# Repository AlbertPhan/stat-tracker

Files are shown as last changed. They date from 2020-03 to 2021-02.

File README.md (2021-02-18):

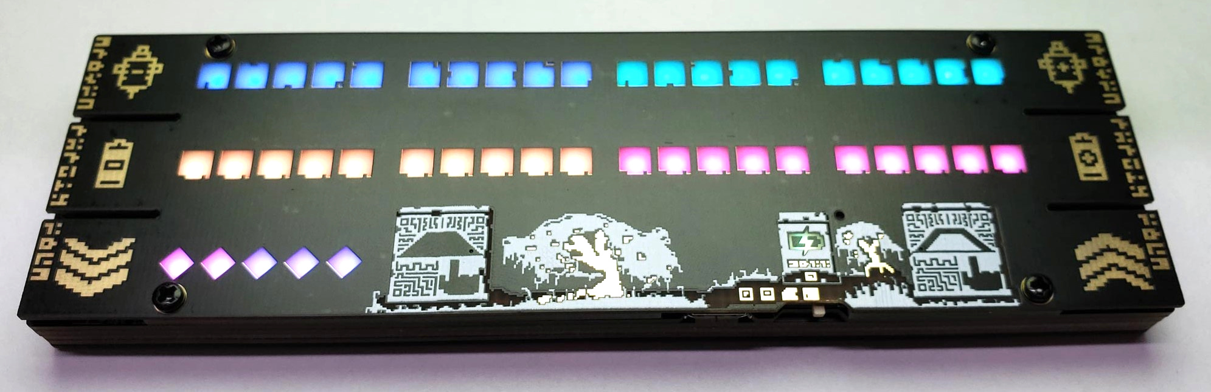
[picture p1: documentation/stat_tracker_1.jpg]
Stat Tracker


### For more pictures and info see:
www.pegasusprototyping.ca/stattracker

# Stat Tracker
The ***Stat Tracker*** is a portable battery powered device that keeps track of ***health, energy, and dashes*** for the Hyper Light Drifter Table Top Role Playing Game. Although it was designed with Hyper Light Drifter in mind, it could be used in other table top games like Dungeons and Dragons. 

Features:

 - Tracks 40 points of Health and Energy and 10 points in Dashes
 - Bright RGB leds for each icon
 - Custom art in Hyper Light Drifter theme
 - Unique Slim PCB sandwich construction with special icons for LED diffusion
 - 6 physical pcb buttons to add/subtract points
 - 2 touch buttons for brightness control
 - Customizable colour palettes including colourblind modes
 - USB micro for charging
 - 8 hours of battery life on default brightness and battery charge indicator icon
 - Stats are saved on power off.

 # Code

 The stat tracker uses a very cheap 50 cent chinese mcu called the CH552. The tool chain setup is explained in https://github.com/Blinkinlabs/ch554_sdcc.

 The stat tracker code is contained in the examples folder "examples/stat_tracker"

 Some c files were created/modified to help use the ch552 such as:
 - button.c     usage of buttons and their states
 - touch.c      touch button usage
 - timer.c      set up timers for millis()

 # Eagle Source files

Eagle Source files are included. (Eagle Version 9.6.1 was used). See README in Eagle files for bom/board information.

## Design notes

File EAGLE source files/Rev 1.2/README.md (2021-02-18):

# Boards
For a full PCB sandwich you will need:
1 Top
1 Middle
1 Bottom
3 Spacers
1 Box Art
Send additional info the board house such as led pinout png and note that the pads on the bottom of the bottom board are supposed to have solder mask (no exposed pad) over them.

# BOM
Bom is located in the GERBER bottom assembly "\Rev 1.2\Gerber\HLD-stat-tracker-bottom_2020-12-04\CAMOutputs\Assembly\HLD-stat-tracker-bottom-BOM.csv"
LEDS used are a 2020 type with SK6812 like pinout (not the same as ws2812-2020). Please triple check the pinouts if you are using something other than leds in the BOM.

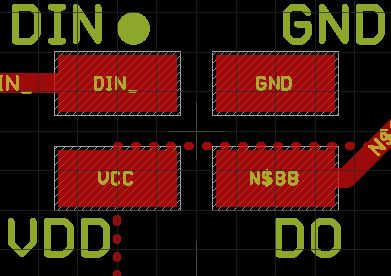
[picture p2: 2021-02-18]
EAGLE source files/Rev 1.2/Gerber/KTR-1010 Pinout.JPG

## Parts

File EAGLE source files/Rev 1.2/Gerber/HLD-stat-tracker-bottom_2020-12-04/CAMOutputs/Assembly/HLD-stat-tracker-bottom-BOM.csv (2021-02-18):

Qty | Value | Device | Package | Parts | Description | MANUFACTURER | PARTNO | POPULARITY | PROD_ID | SPICEPREFIX | VALUE
1 |  | PTC0805 | WCAP-CSGP_0805_H1.25_R | PTC1 | PTC (Resettable Fuse) | Jinrui Electronic Materials Co. | JK-SMD0805-075
1 |  | USB_MICRO-BSINK-PLATE | USB-B-MICRO-SMD-SINK-PLATE | J1 | USB Type Micro-B Connector | Jing Extension of the Electronic Co. | C40957
2 | 100nF | C-EUC0805K | C0805K | C1 | C2 | CAPACITOR | European symbol |  | ?
6 | 10k | R-US_R0805S | R0805S | R1 | R3 | R5 | R6 | R7 | R8 | RESISTOR | American symbol |  | ?
4 | 10uF | C-EUC0805K | C0805K | C3 | C4 | C5 | C9 | CAPACITOR | European symbol |  | ?
1 | 2k | R-US_R0805S | R0805S | R2 | RESISTOR | American symbol |  | ?
1 | 3.9k | R-US_R0805S | R0805S | R4 | RESISTOR | American symbol |  | ?
1 | 4.7uH | INDUCTOR2012 | BEADC2012X105N | L1 | NRS6014 Inductor | INPAQ | C315723
1 | 7MM-SLIDE-SWITCH | 7MM-SLIDE-SWITCH | 7MM-SMD-SLIDE-SWITCH | PWR | PN: SSSS811101 7mm SMD SLIDE SWITCH | XKB Enterprise | SK-3296S-01-L1
1 | AP2302B | MOSFET-NREFLOW | SOT23-R | Q2 | N-Channel Mosfet | HX(hengjiaxing) | AP2302B
1 | B5819LW | DIODESOD-123 | SOD-123 | D1 | Diode | Guangdong Hottech | B5819LW
1 | CH552SOP16-HANDSOLDER | CH552SOP16-HANDSOLDER | SOP16-HANDSOLDER | IC1 | Microcontroller | WCH(Jiangsu Qin Heng) | CH552G
1 | HX2301A | MOSFET-P | SOT23-R | Q1 | P-Channel Mosfet | HX(hengjiaxing) | HX2301A
46 | KTR-1010RGBC-1812-4 | KTR-1010RGBC-1812-4 | SK6812-2020 | STATUS | U$1 | U$2 | U$3 | U$4 | U$5 | U$6 | U$7 | U$8 | U$9 | U$10 | U$11 | U$12 | U$13 | U$14 | U$15 | U$16 | U$17 | U$18 | U$19 | U$20 | U$21 | U$22 | U$23 | U$24 | U$25 | U$26 | U$27 | U$28 | U$29 | U$30 | U$31 | U$32 | U$33 | U$34 | U$35 | U$36 | U$37 | U$38 | U$39 | U$40 | U$41 | U$42 | U$43 | U$44 | U$45 | Addressable RGD LED similiar to SK6812-2020. | KTRLIGHT | KTR-1010RGBC-1812-4
1 | MCP73832 | MCP73831 | SOT23-5 | U1 | Miniature single cell | fully integrated Li-Ion | Li-polymer charge management controller | Microchip Tech | MCP73832
1 | MT3540 | AP3012 | SOT23-5 | U2 | AP3012 | XI'AN Aerosemi Tech | MT3540
3 | SPRING-CONTACT | SPRING-CONTACT | 818000905-SPRING-CONTACT | GND | TIN1 | TIN2 |  | ECT | ECT818000905
7 | TACTSW | TACTSW | 3MM-TACT | BOOT | DP+ | DP- | EP+ | EP- | HP+ | HP- |  | SHOU HAN | TS3315A
4 |  |  |  |  | M2 Threaded Standoff OD 3.12mm length 4mm
4 |  |  |  |  | M2 Button Philips Head 3 mm length black
4 |  |  |  |  | M2 Button Philips Head 6 mm length black
1 |  |  |  |  | Lipo Battery 630 Mah 403443 (4 mm thick x 34 mm x 43 mm)
4

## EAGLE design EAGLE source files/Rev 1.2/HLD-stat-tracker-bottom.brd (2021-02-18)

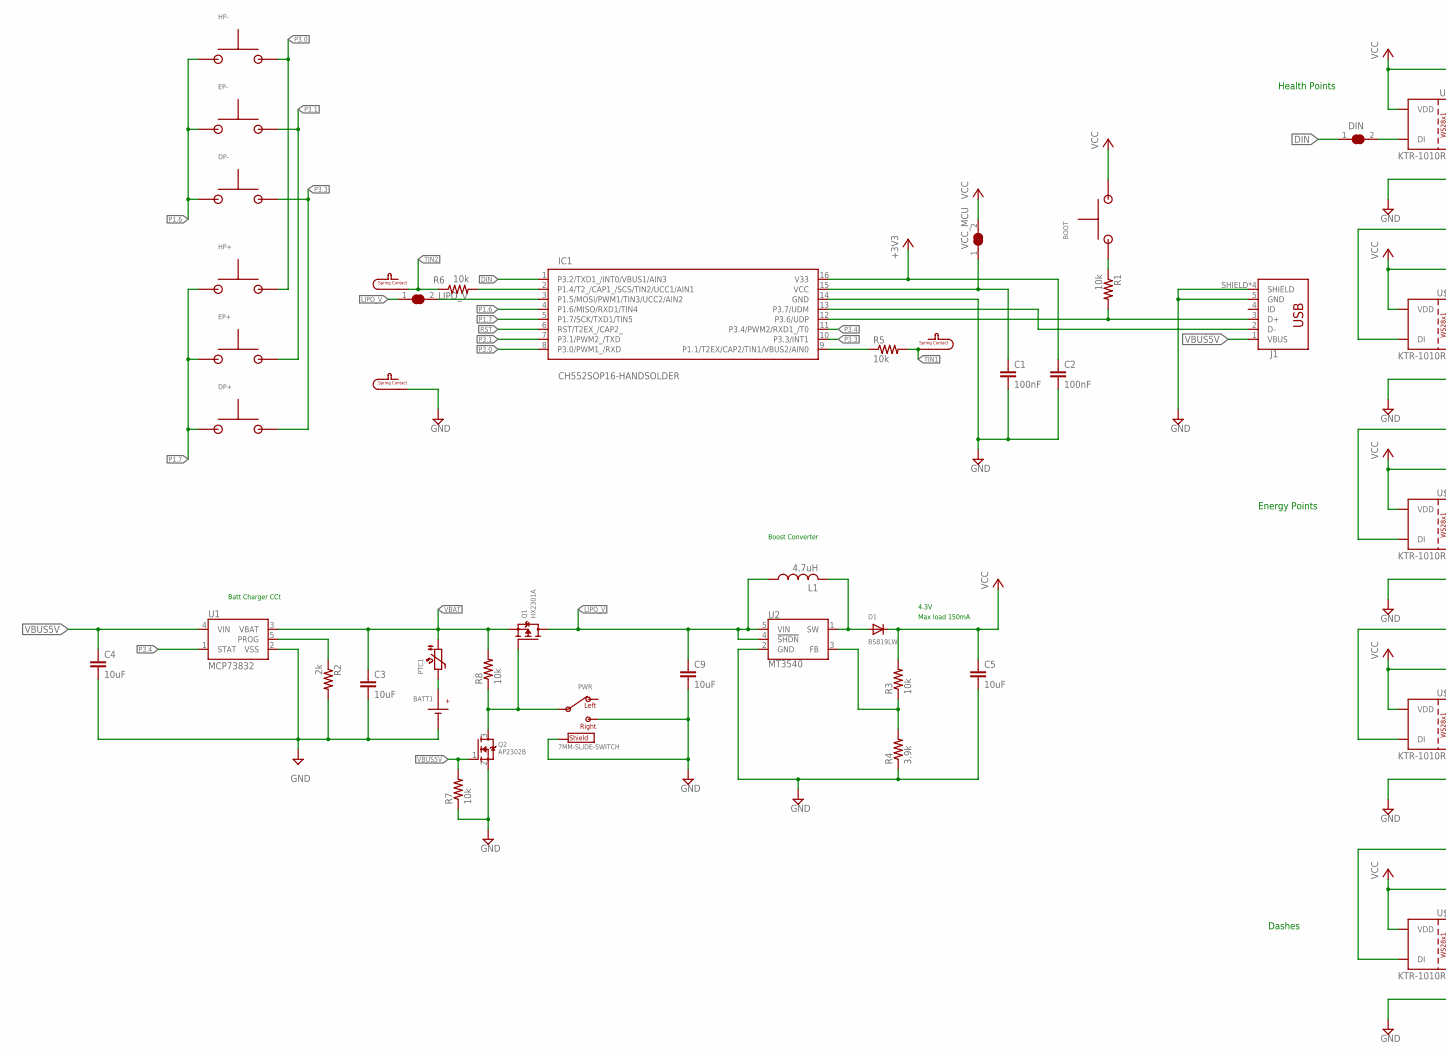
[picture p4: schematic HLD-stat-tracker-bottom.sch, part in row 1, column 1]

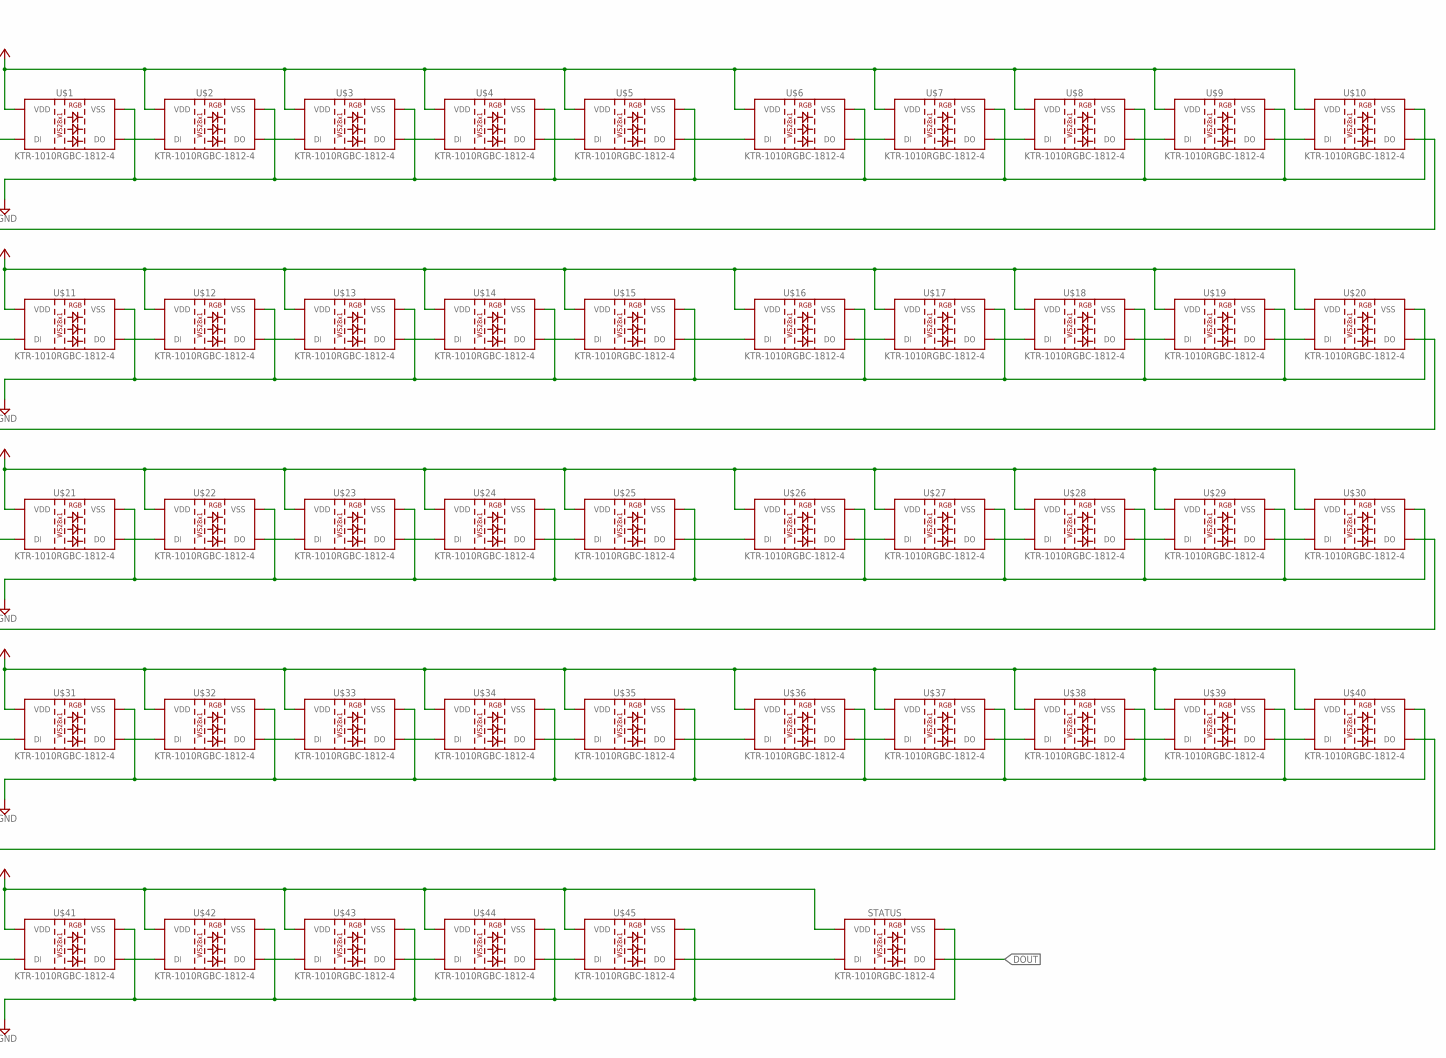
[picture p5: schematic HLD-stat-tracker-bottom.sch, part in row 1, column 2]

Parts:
BATT1: BATT+; BATT+PAD; PARTNO ?
BATT1-: BATT-; BATT-PAD; PARTNO ?
BOOT: TACTSW; 3MM-TACT
C1, C2: 100nF; C0805K; PARTNO ?
C3, C4, C5, C9: 10uF; C0805K; PARTNO ?
D1: B5819LW; SOD-123; PARTNO B5819LW
DIN: SOLDERJUMPER-NC; SOLDERJUMPER_CLOSEDWIRE_SMALL
DP+: TACTSW; 3MM-TACT
DP-: TACTSW; 3MM-TACT
EP+: TACTSW; 3MM-TACT
EP-: TACTSW; 3MM-TACT
GND: SPRING-CONTACT; 818000905-SPRING-CONTACT
HP+: TACTSW; 3MM-TACT
HP-: TACTSW; 3MM-TACT; PARTNO TS3315A
IC1: CH552SOP16-HANDSOLDER; SOP16-HANDSOLDER
J1: USB_MICRO-BSINK-PLATE; USB-B-MICRO-SMD-SINK-PLATE
L1: 4.7uH; BEADC2012X105N
LIPO_V: SOLDERJUMPER-NC; SOLDERJUMPER_CLOSEDWIRE_SMALL
PTC1: PTC0805; WCAP-CSGP_0805_H1.25_R
PWR: 7MM-SLIDE-SWITCH; 7MM-SMD-SLIDE-SWITCH
Q1: HX2301A; SOT23-R
Q2: AP2302B; SOT23-R
R1, R3, R5, R6, R7, R8: 10k; R0805S; PARTNO ?
R2: 2k; R0805S; PARTNO ?
R4: 3.9k; R0805S; PARTNO ?
STATUS: KTR-1010RGBC-1812-4; SK6812-2020
TIN1, TIN2: SPRING-CONTACT; 818000905-SPRING-CONTACT
U1: MCP73832; SOT23-5; PARTNO MCP73832
U2: MT3540; SOT23-5; PARTNO MT3540
U$1, U$2, U$3, U$4, U$5, U$6, U$7, U$8, U$9, U$10, U$11, U$12, U$13, U$14, U$15, U$16, U$17, U$18, U$19, U$20, U$21, U$22, U$23, U$24, U$25, U$26, U$27, U$28, U$29, U$30, U$31, U$32, U$33, U$34, U$35, U$36, U$37, U$38, U$39, U$40, U$41, U$42, U$43, U$44, U$45: KTR-1010RGBC-1812-4; SK6812-2020
VCC_MCU: SOLDERJUMPER-NC; SOLDERJUMPER_CLOSEDWIRE_SMALL

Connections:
+3V3: C2.1, IC1.16 (V33)
DIN: DIN.1, IC1.1 (P3.2/TXD1_/INT0/VBUS1/AIN3)
DIN_: DIN.2, U$1.DIN (DI)
DOUT: STATUS.DOUT (DO)
FB: R3.1, R4.2, U2.3 (FB)
GND: BATT1-.P$1, C1.2, C2.2, C3.2, C4.2, C5.2, C9.2, GND.P$1, IC1.14 (GND), J1.5 (GND), J1.SHIELD, J1.SHIELD2 (SHIELD), J1.SHIELD3 (SHIELD), J1.SHIELD4 (SHIELD), PWR.3, PWR.GND@1 (SHIELD), PWR.GND@2 (SHIELD), PWR.GND@3 (SHIELD), PWR.GND@4 (SHIELD), Q2.2 (S), R2.2, R4.1, R7.1, STATUS.VSS, U1.2 (VSS), U2.2 (GND), U$1.VSS, U$2.VSS, U$3.VSS, U$4.VSS, U$5.VSS, U$6.VSS, U$7.VSS, U$8.VSS, U$9.VSS, U$10.VSS, U$11.VSS, U$12.VSS, U$13.VSS, U$14.VSS, U$15.VSS, U$16.VSS, U$17.VSS, U$18.VSS, U$19.VSS, U$20.VSS, U$21.VSS, U$22.VSS, U$23.VSS, U$24.VSS, U$25.VSS, U$26.VSS, U$27.VSS, U$28.VSS, U$29.VSS, U$30.VSS, U$31.VSS, U$32.VSS, U$33.VSS, U$34.VSS, U$35.VSS, U$36.VSS, U$37.VSS, U$38.VSS, U$39.VSS, U$40.VSS, U$41.VSS, U$42.VSS, U$43.VSS, U$44.VSS, U$45.VSS
LIPO_V: C9.1, L1.1, LIPO_V.1, Q1.3 (D), U2.4 (!SHDN!), U2.5 (VIN)
LIPO_V_MCU: IC1.3 (P1.5/MOSI/PWM1/TIN3/UCC2/AIN2), LIPO_V.2
unnamed: IC1.9 (P1.1/T2EX/CAP2/TIN1/VBUS2/AIN0), R5.1
unnamed: BATT1.P$1, PTC1.2
unnamed: IC1.2 (P1.4/T2_/CAP1_/SCS/TIN2/UCC1/AIN1), R6.2
unnamed: PWR.2, Q1.1 (G), Q2.3 (D), R8.1
unnamed: U$1.DOUT (DO), U$2.DIN (DI)
unnamed: U$6.DOUT (DO), U$7.DIN (DI)
unnamed: R2.1, U1.5 (PROG)
unnamed: U$20.DOUT (DO), U$21.DIN (DI)
unnamed: U$11.DOUT (DO), U$12.DIN (DI)
unnamed: U$16.DOUT (DO), U$17.DIN (DI)
unnamed: U$12.DOUT (DO), U$13.DIN (DI)
unnamed: U$13.DOUT (DO), U$14.DIN (DI)
unnamed: U$14.DOUT (DO), U$15.DIN (DI)
unnamed: U$15.DOUT (DO), U$16.DIN (DI)
unnamed: U$2.DOUT (DO), U$3.DIN (DI)
unnamed: U$3.DOUT (DO), U$4.DIN (DI)
unnamed: U$4.DOUT (DO), U$5.DIN (DI)
unnamed: U$5.DOUT (DO), U$6.DIN (DI)
unnamed: U$7.DOUT (DO), U$8.DIN (DI)
unnamed: U$8.DOUT (DO), U$9.DIN (DI)
unnamed: U$9.DOUT (DO), U$10.DIN (DI)
unnamed: U$17.DOUT (DO), U$18.DIN (DI)
unnamed: U$18.DOUT (DO), U$19.DIN (DI)
unnamed: U$19.DOUT (DO), U$20.DIN (DI)
unnamed: U$10.DOUT (DO), U$11.DIN (DI)
unnamed: U$21.DOUT (DO), U$22.DIN (DI)
unnamed: U$26.DOUT (DO), U$27.DIN (DI)
unnamed: U$22.DOUT (DO), U$23.DIN (DI)
unnamed: U$23.DOUT (DO), U$24.DIN (DI)
unnamed: U$24.DOUT (DO), U$25.DIN (DI)
unnamed: U$25.DOUT (DO), U$26.DIN (DI)
unnamed: U$27.DOUT (DO), U$28.DIN (DI)
unnamed: U$28.DOUT (DO), U$29.DIN (DI)
unnamed: U$29.DOUT (DO), U$30.DIN (DI)
unnamed: U$31.DOUT (DO), U$32.DIN (DI)
unnamed: U$36.DOUT (DO), U$37.DIN (DI)
unnamed: U$32.DOUT (DO), U$33.DIN (DI)
unnamed: U$33.DOUT (DO), U$34.DIN (DI)
unnamed: U$34.DOUT (DO), U$35.DIN (DI)
unnamed: U$35.DOUT (DO), U$36.DIN (DI)
unnamed: U$37.DOUT (DO), U$38.DIN (DI)
unnamed: U$38.DOUT (DO), U$39.DIN (DI)
unnamed: U$39.DOUT (DO), U$40.DIN (DI)
unnamed: U$30.DOUT (DO), U$31.DIN (DI)
unnamed: U$41.DOUT (DO), U$42.DIN (DI)
unnamed: U$42.DOUT (DO), U$43.DIN (DI)
unnamed: U$43.DOUT (DO), U$44.DIN (DI)
unnamed: U$44.DOUT (DO), U$45.DIN (DI)
unnamed: STATUS.DIN (DI), U$45.DOUT (DO)
unnamed: U$40.DOUT (DO), U$41.DIN (DI)
unnamed: BOOT.1, BOOT.2, R1.1
P1.6: DP-.1, DP-.2, EP-.1, EP-.2, HP-.1, HP-.2, IC1.4 (P1.6/MISO/RXD1/TIN4)
P1.7: DP+.1, DP+.2, EP+.1, EP+.2, HP+.1, HP+.2, IC1.5 (P1.7/SCK/TXD1/TIN5)
P3.0: HP+.3, HP+.4, HP-.3, HP-.4, IC1.8 (P3.0/PWM1_/RXD)
P3.1: EP+.3, EP+.4, EP-.3, EP-.4, IC1.7 (P3.1/PWM2_/TXD)
P3.3: DP+.3, DP+.4, DP-.3, DP-.4, IC1.10 (P3.3/INT1)
P3.4: IC1.11 (P3.4/PWM2/RXD1_/T0), U1.1 (STAT)
RST: IC1.6 (RST/T2EX_/CAP2_)
SW: D1.A, L1.2, U2.1 (SW)
TIN1: R5.2, TIN1.P$1
TIN2: R6.1, TIN2.P$1
UDM: IC1.13 (P3.7/UDM), J1.2 (D-)
UDP: IC1.12 (P3.6/UDP), J1.3 (D+), R1.2
VBAT: C3.1, PTC1.1, Q1.2 (S), R8.2, U1.3 (VBAT)
VBUS5V: C4.1, J1.1 (VBUS), Q2.1 (G), R7.2, U1.4 (VIN)
VCC: BOOT.3, BOOT.4, C5.1, D1.C, R3.2, STATUS.VDD, U$1.VDD, U$2.VDD, U$3.VDD, U$4.VDD, U$5.VDD, U$6.VDD, U$7.VDD, U$8.VDD, U$9.VDD, U$10.VDD, U$11.VDD, U$12.VDD, U$13.VDD, U$14.VDD, U$15.VDD, U$16.VDD, U$17.VDD, U$18.VDD, U$19.VDD, U$20.VDD, U$21.VDD, U$22.VDD, U$23.VDD, U$24.VDD, U$25.VDD, U$26.VDD, U$27.VDD, U$28.VDD, U$29.VDD, U$30.VDD, U$31.VDD, U$32.VDD, U$33.VDD, U$34.VDD, U$35.VDD, U$36.VDD, U$37.VDD, U$38.VDD, U$39.VDD, U$40.VDD, U$41.VDD, U$42.VDD, U$43.VDD, U$44.VDD, U$45.VDD, VCC_MCU.2
VCC_MCU: C1.1, IC1.15 (VCC), VCC_MCU.1

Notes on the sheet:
Health Points
Energy Points
Dashes
Batt Charger CCt
Boost Converter
Max load 150mA
4.3V

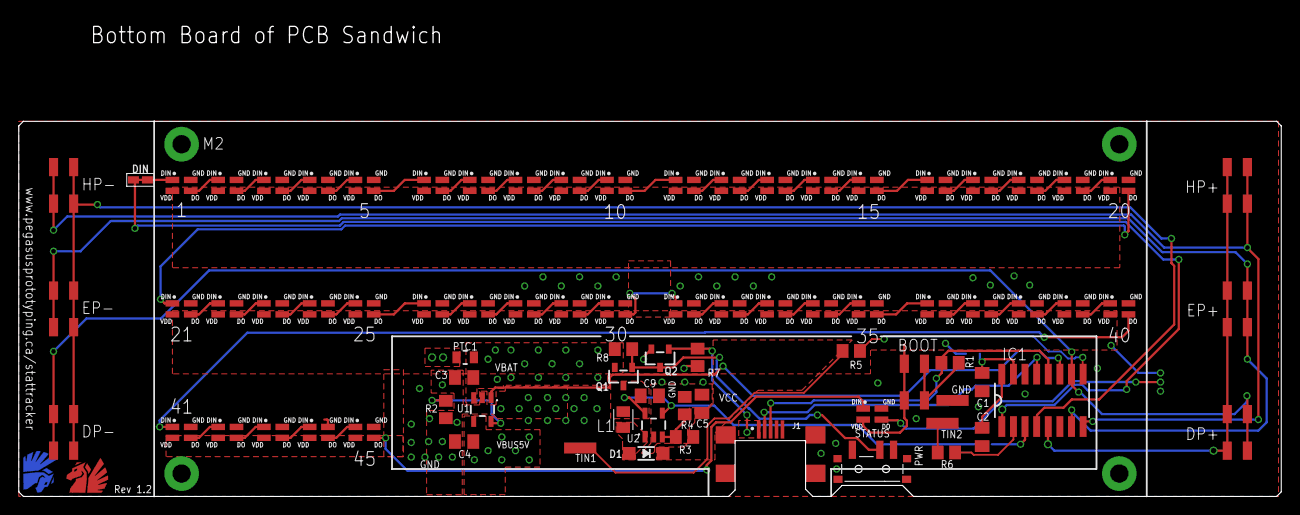
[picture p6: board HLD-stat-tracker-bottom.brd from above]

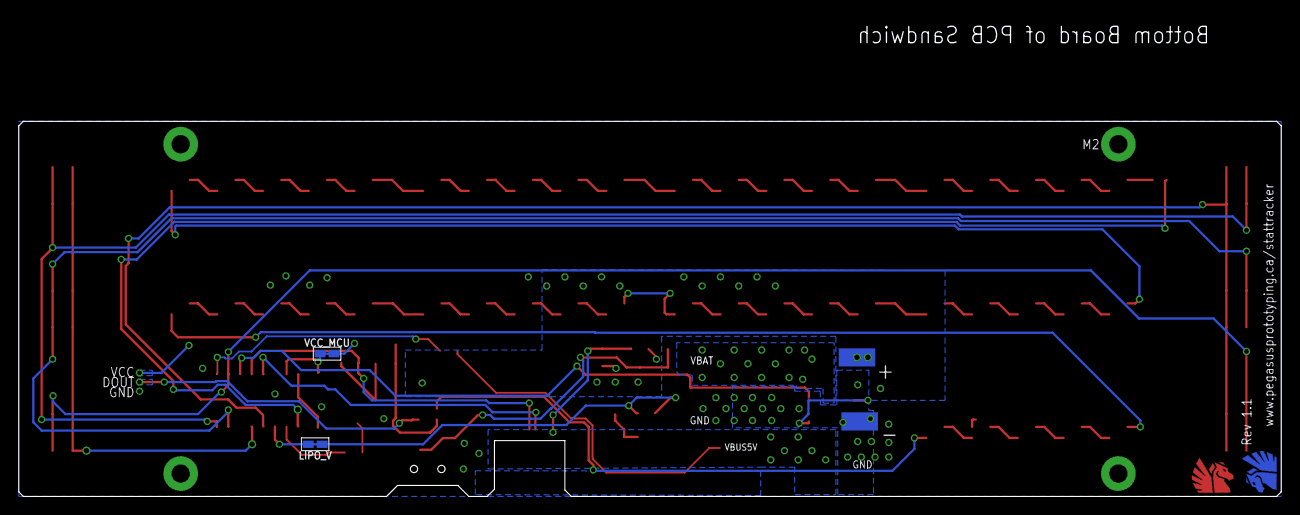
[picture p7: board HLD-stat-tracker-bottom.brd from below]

Board: 2 copper layers, 138.0 x 41.0 mm, 87 parts (5 on the bottom side), 73 nets.

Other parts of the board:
U$52, U$53: PEGASUSPROTOTYPING_5MM_COPPER

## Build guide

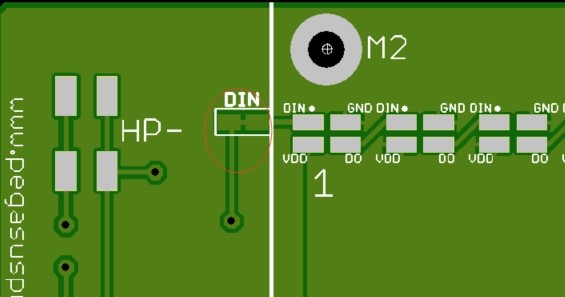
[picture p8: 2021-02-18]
EAGLE source files/Rev 1.2/Gerber/No soldering pads 2.jpg

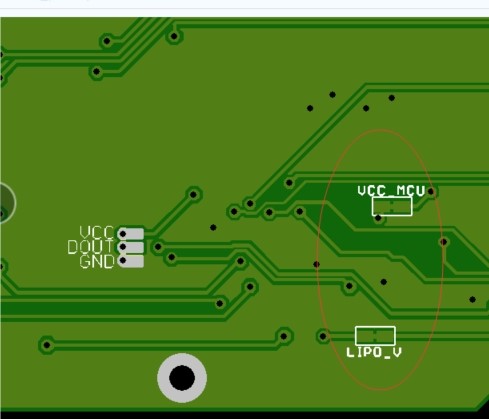
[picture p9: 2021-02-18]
EAGLE source files/Rev 1.2/Gerber/No soldering pads.jpg

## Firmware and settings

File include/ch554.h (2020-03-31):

/*--------------------------------------------------------------------------
CH554.H
Header file for CH554 microcontrollers.
****************************************
**  Copyright  (C)  W.ch  1999-2014   **
**  Web:              http://wch.cn   **
****************************************
--------------------------------------------------------------------------*/

#ifndef __CH554_H__
#define __CH554_H__

#include <compiler.h>

/*----- SFR --------------------------------------------------------------*/
/*  sbit are bit addressable, others are byte addressable */

/*  System Registers  */
SFR(PSW,	0xD0);	// program status word
   SBIT(CY,	0xD0, 7);	// carry flag
   SBIT(AC,	0xD0, 6);	// auxiliary carry flag
   SBIT(F0,	0xD0, 5);	// bit addressable general purpose flag 0
   SBIT(RS1,	0xD0, 4);	// register R0-R7 bank selection high bit
   SBIT(RS0,	0xD0, 3);	// register R0-R7 bank selection low bit
#define MASK_PSW_RS       0x18      // bit mask of register R0-R7 bank selection
// RS1 & RS0: register R0-R7 bank selection
//    00 - bank 0, R0-R7 @ address 0x00-0x07
//    01 - bank 1, R0-R7 @ address 0x08-0x0F
//    10 - bank 2, R0-R7 @ address 0x10-0x17
//    11 - bank 3, R0-R7 @ address 0x18-0x1F
   SBIT(OV,	0xD0, 2);	// overflow flag
   SBIT(F1,	0xD0, 1);	// bit addressable general purpose flag 1
   SBIT(P,	0xD0, 0);	// ReadOnly: parity flag
SFR(ACC,	0xE0);	// accumulator
SFR(B,	0xF0);	// general purpose register B
SFR(SP,	0x81);	// stack pointer
//sfr16 DPTR          = 0x82;         // DPTR pointer, little-endian
SFR(DPL,	0x82);	// data pointer low
SFR(DPH,	0x83);	// data pointer high
SFR(SAFE_MOD,	0xA1);	// WriteOnly: writing safe mode
//sfr CHIP_ID         = 0xA1;         // ReadOnly: reading chip ID
#define CHIP_ID           SAFE_MOD
SFR(GLOBAL_CFG,	0xB1);	// global config, Write@SafeMode
#define bBOOT_LOAD        0x20      // ReadOnly: boot loader status for discriminating BootLoader or Application: set 1 by power on reset, clear 0 by software reset
#define bSW_RESET         0x10      // software reset bit, auto clear by hardware
#define bCODE_WE          0x08      // enable flash-ROM (include code & Data-Flash) being program or erasing: 0=writing protect, 1=enable program and erase
#define bDATA_WE          0x04      // enable Data-Flash (flash-ROM data area) being program or erasing: 0=writing protect, 1=enable program and erase
#define bLDO3V3_OFF       0x02      // disable 5V->3.3V LDO: 0=enable LDO for USB and internal oscillator under 5V power, 1=disable LDO, V33 pin input external 3.3V power
#define bWDOG_EN          0x01      // enable watch-dog reset if watch-dog timer overflow: 0=as timer only, 1=enable reset if timer overflow

/* Clock and Sleep and Power Registers */
SFR(PCON,	0x87);	// power control and reset flag
#define SMOD              0x80      // baud rate selection for UART0 mode 1/2/3: 0=slow(Fsys/128 @mode2, TF1/32 @mode1/3, no effect for TF2),
                                    //   1=fast(Fsys/32 @mode2, TF1/16 @mode1/3, no effect for TF2)
#define bRST_FLAG1        0x20      // ReadOnly: recent reset flag high bit
#define bRST_FLAG0        0x10      // ReadOnly: recent reset flag low bit
#define MASK_RST_FLAG     0x30      // ReadOnly: bit mask of recent reset flag
#define RST_FLAG_SW       0x00
#define RST_FLAG_POR      0x10
#define RST_FLAG_WDOG     0x20
#define RST_FLAG_PIN      0x30
// bPC_RST_FLAG1 & bPC_RST_FLAG0: recent reset flag
//    00 - software reset, by bSW_RESET=1 @(bBOOT_LOAD=0 or bWDOG_EN=1)
//    01 - power on reset
//    10 - watch-dog timer overflow reset
//    11 - external input manual reset by RST pin
#define GF1               0x08      // general purpose flag bit 1
#define GF0               0x04      // general purpose flag bit 0
#define PD                0x02      // power-down enable bit, auto clear by wake-up hardware
SFR(CLOCK_CFG,	0xB9);	// system clock config: lower 3 bits for system clock Fsys, Write@SafeMode
#define bOSC_EN_INT       0x80      // internal oscillator enable and original clock selection: 1=enable & select internal clock, 0=disable & select external clock
#define bOSC_EN_XT        0x40      // external oscillator enable, need quartz crystal or ceramic resonator between XI and XO pins
#define bWDOG_IF_TO       0x20      // ReadOnly: watch-dog timer overflow interrupt flag, cleared by reload watch-dog count or auto cleared when MCU enter interrupt routine
#define bROM_CLK_FAST     0x10      // flash-ROM clock frequency selection: 0=normal(for Fosc>=16MHz), 1=fast(for Fosc<16MHz)
#define bRST              0x08      // ReadOnly: pin RST input
#define bT2EX_            0x08      // alternate pin for T2EX
#define bCAP2_            0x08      // alternate pin for CAP2
#define MASK_SYS_CK_SEL   0x07      // bit mask of system clock Fsys selection
/*
   Fxt = 24MHz(8MHz~25MHz for non-USB application), from external oscillator @XI&XO
   Fosc = bOSC_EN_INT ? 24MHz : Fxt
   Fpll = Fosc * 4 => 96MHz (32MHz~100MHz for non-USB application)
   Fusb4x = Fpll / 2 => 48MHz (Fixed)
              MASK_SYS_CK_SEL[2] [1] [0]
   Fsys = Fpll/3   =  32MHz:  1   1   1
   Fsys = Fpll/4   =  24MHz:  1   1   0
   Fsys = Fpll/6   =  16MHz:  1   0   1
   Fsys = Fpll/8   =  12MHz:  1   0   0
   Fsys = Fpll/16  =   6MHz:  0   1   1
   Fsys = Fpll/32  =   3MHz:  0   1   0
   Fsys = Fpll/128 = 750KHz:  0   0   1
   Fsys = Fpll/512 =187.5KHz: 0   0   0
*/
SFR(WAKE_CTRL,	0xA9);	// wake-up control, Write@SafeMode
#define bWAK_BY_USB       0x80      // enable wake-up by USB event
#define bWAK_RXD1_LO      0x40      // enable wake-up by RXD1 low level
#define bWAK_P1_5_LO      0x20      // enable wake-up by pin P1.5 low level
#define bWAK_P1_4_LO      0x10      // enable wake-up by pin P1.4 low level
#define bWAK_P1_3_LO      0x08      // enable wake-up by pin P1.3 low level
#define bWAK_RST_HI       0x04      // enable wake-up by pin RST high level
#define bWAK_P3_2E_3L     0x02      // enable wake-up by pin P3.2 (INT0) edge or pin P3.3 (INT1) low level
#define bWAK_RXD0_LO      0x01      // enable wake-up by RXD0 low level
SFR(RESET_KEEP,	0xFE);	// value keeper during reset
SFR(WDOG_COUNT,	0xFF);	// watch-dog count, count by clock frequency Fsys/65536
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

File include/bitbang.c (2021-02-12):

#include <stdint.h>

#include <ch554.h>
#include "bitbang.h"

// Bitbang.c is used to bitbang the addressable led protocol for the ch55x @ 16 Mhz
// Setup: In main, please set up the SBIT with the LED label for your pin. eg.
// #define LED_PIN 2	// addressable led data pin
// SBIT(LED, PORT3, LED_PIN); // LED is used in bitbang.c
// also include which led you want to use eg. for sk6812_2020
// #define bitbang(led_count,led_data)	bitbangSk6812_2020(led_count, led_data)	// choosing correct led (see bitbang.h)
// call the setup function
// bitbangSetup(3,LED_PIN); // using 3.2 pin as led pin
//

// Choose port 3 or 1 and pin to use
void bitbangSetup(uint8_t port, uint8_t pin)
{
    // Configure Pin 3.1 as GPIO output
    if(port == 3)
    {
        P3_MOD_OC &= ~(1<<pin); // Set Push pull output mode
        P3_DIR_PU |= (1<<pin);  // Set to output mode
    }
    else if (port == 1)
    {
        P1_MOD_OC &= ~(1<<pin); // Set Push pull output mode
        P1_DIR_PU |= (1<<pin);  // Set to output mode
    }
    
}

void bitbangWs2812( uint8_t ledCount, __xdata uint8_t * ledData )
{
    EA = 0; // Disable global interrupts
    ledCount;
    ledData;

    // Bitbang routine
    // Input parameters: (determined by compilation)
    // * byteCount should be allocated in dpl
    // * ledData should be allocated with name '_bitbangWs2812_PARAM_2'

    // Strategy:
    // * Keep the data memory pointer in DPTR
    // * Keep ledCount in r2
    // * Store bitCount in r3
    // * Store the current data variable in ACC

    //  TODO: What context needs to be pushed/popped?

    __asm

    mov r2, dpl             ; Load the LED count into r2

    mov dpl, _bitbangWs2812_PARM_2  ; Load the LED data start address into DPTR
    mov dph, (_bitbangWs2812_PARM_2 + 1)

    00001$:                 ; byte loop

// Red byte
        movx a,@dptr        ; Load the current LED data value into the accumulator (1)
        inc dptr            ; and advance the counter for the next LED data value (1)

        mov r3, #8          ; Set up the bit loop (2)
    00002$:                 ; red bit loop
        setb _LED           ; Begin bit cycle- set bit high (2)

        nop                 ; Tune this count by hand, want ~.4uS (1*2)
        nop

        rlc A               ; Shift the LED data value left to get the high bit (1)
        mov _LED, C         ; Set the output bit high if the current bit is high, (2)
                            ; otherwise set it low

        nop                 ; Tune this count by hand, want ~.4uS (1*2)
        nop
        nop

        clr _LED            ; final part of bit cycle, set bit low (2)

//        nop                 ; Tune this count by hand, want ~.45uS
//        nop

        djnz r3, 00002$     ; If there are more bits in this byte (2, ?)

// Green byte
        movx a,@dptr        ; Load the current LED data value into the accumulator (1)
        inc dptr            ; and advance the counter for the next LED data value (1)

        mov r3, #8          ; Set up the bit loop (2)
    00003$:                 ; green bit loop
        setb _LED           ; Begin bit cycle- set bit high (2)

        nop                 ; Tune this count by hand, want ~.4uS (1*2)
        nop
        

        rlc A               ; Shift the LED data value left to get the high bit (1)
        mov _LED, C         ; Set the output bit high if the current bit is high, (2)
                            ; otherwise set it low

        nop                 ; Tune this count by hand, want ~.4uS (1*2)
        nop
        nop

        clr _LED            ; final part of bit cycle, set bit low (2)

//        nop                 ; Tune this count by hand, want ~.45uS
//        nop

        djnz r3, 00003$     ; If there are more bits in this byte (2, ?)

// Blue byte
        movx a,@dptr        ; Load the current LED data value into the accumulator (1)
        inc dptr            ; and advance the counter for the next LED data value (1)

        mov r3, #8          ; Set up the bit loop (2)
    00004$:                 ; blue bit loop
        setb _LED           ; Begin bit cycle- set bit high (2)

        nop                 ; Tune this count by hand, want ~.4uS (1*2)
        nop

        rlc A               ; Shift the LED data value left to get the high bit (1)
        mov _LED, C         ; Set the output bit high if the current bit is high, (2)
                            ; otherwise set it low

        nop                 ; Tune this count by hand, want ~.4uS (1*2)
        nop
        nop

        clr _LED            ; final part of bit cycle, set bit low (2)

//        nop                 ; Tune this count by hand, want ~.45uS
//        nop

        djnz r3, 00004$     ; If there are more bits in this byte (2, ?)


        djnz r2, 00001$     ; If there are more LEDs (2, ?)

    __endasm;
    EA = 1; // enable global interrupts
}


// Modified to be compatible with sk6812-2020,KTR1010 and potentially other 2020 small addressable leds. (not tested on ws2812-2020 which have a different T1L max)
// T0H = 320ns
// T0L = 944ns
// T1H = 688ns
// T1L = 560ns
// FMHZ = 12 Mhz
void bitbangSk6812_2020( uint8_t ledCount, __xdata uint8_t * ledData )
{
    EA = 0; // Disable global interrupts
    ledCount;
    ledData;
	

    // Bitbang routine
    // Input parameters: (determined by compilation)
    // * byteCount should be allocated in dpl
    // * ledData should be allocated with name '_bitbangWs2812_PARAM_2'

    // Strategy:
    // * Keep the data memory pointer in DPTR
    // * Keep ledCount in r2
    // * Store bitCount in r3
    // * Store the current data variable in ACC

    //  TODO: What context needs to be pushed/popped?

    __asm

    mov r2, dpl             ; Load the LED count into r2

    mov dpl, _bitbangWs2812_PARM_2  ; Load the LED data start address into DPTR
    mov dph, (_bitbangWs2812_PARM_2 + 1)

    00001$:                 ; byte loop

// Red byte
        movx a,@dptr        ; Load the current LED data value into the accumulator (1)
        inc dptr            ; and advance the counter for the next LED data value (1)

        mov r3, #8          ; Set up the bit loop (2)
    00002$:                 ; red bit loop
        setb _LED           ; Begin bit cycle- set bit high (2)

        nop                 ; Tune this count by hand, want ~.4uS (1*2)
        nop

        rlc A               ; Shift the LED data value left to get the high bit (1)
        mov _LED, C         ; Set the output bit high if the current bit is high, (2)
                            ; otherwise set it low

        nop                 ; Tune this count by hand, want ~.4uS (1*2)
        nop
        nop
		nop
		
        

        clr _LED            ; final part of bit cycle, set bit low (2)

        nop                 ; Tune this count by hand, want ~.45uS
        nop
		nop

        djnz r3, 00002$     ; If there are more bits in this byte (2, ?)
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

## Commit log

2020-03-31 Initial Commit
    Most LED and button Functionality complete.
2020-04-02 Got touch key buttons working
    Added touch.c and touch.h. the chinese examples weren't working so I redid all the code.
    Started copying over some usb cdc files for the future
2020-04-04 Added millis() with timer0
    fixed map() function
    fixed battery color getting mapped twice incorrectly
    renamed colors to hsv for better tab completion
    added battery and timer debug states
    added set_battery_icon_led() for setting battery colours
    added clear_display()
    [main.c]
2020-04-06 Fixed main loop timing issue and added USB for debugging
    Main loop would intermittenly break - causing the main loop to run as fast as it could. Adding an additional check for (prev_millis < current_millis) seemed to fix it. See line 554 in main.c
    USB stuff was added and can be enabled with a define for debugging.
    [hardware.h, main.c, usb-cdc.c]
2020-04-11 Lots of fixes and updates
    A lot of the charging status has been updated
    Major timing bug fixed ( thought to be fixed before but wasnt) - Timer ISR was happening during 4 byte copy of millis() causing errors.
    Added fade struct to help with fading batt icon
    Display dims when low batt
    Flashing on low batt
    Button states being worked on to implement retriggering
    [main.c]
2020-04-13 Updated fully charged button icon behavior
2020-04-14 Added retrigger() to button functionality and separated it to button.c
    button debouncing added to button.c
    It uses lock-out interval style debouncing
2020-04-15 Fixed battery icon fading after constant voltage timeout.
    Define didn't seem to like (60*1000) so changed to single number i.e 60000 or 300000 for 3 minutes.
    Also fixed some include issues in button.c by adding ch554.h in the timer.h
    [main.c]
2020-04-17 Added a long_held state for tkey in button.c
    Changed up BUTTON state to debug the touchkeys instead of dash button.
2020-04-18 Changed to 16 bit for button timing to save space
    Don't need the extra 16 bits for button timing.
    Updated button debug state to show data on any button pressed
2020-04-19 Added a way to check if button state was long held and deactivated
2020-04-20 Changed how retrigger() works
    retrigger now does not activate on first press.
    Now we can use long_held() without activating the button on the initial press. This is useful for going into configuration states.
2020-07-21 Rev 1.0 Board working
    Updated touch code for new board.
    Added charging status screen when charging
    Adjusted ADC values for new 4.28 VCC
    Fixed Battery led bars showing incorrect voltage/charge state
    Adjusted min brightness values during fading to stop hue changes
    Adjusted bitbang timing for ws2812 leds to fix flickering leds. (May require more testing)
    [bitbang.c, main.c]
2020-07-22 Brightness is now saved between resets
    [main.c]
2020-09-28 Changed how fade animating works
    fading now works by grabbing the correct fading frame to be displayed
    while an update fade function updates the animation once per loop.
    ws2812 example bitbanging was adjusted to provide correct timing for the
    ws2812-2020 version of the led
    [bitbang.c, main.c]
2021-02-12 Addressable LED bitbang library cleaned up
    -Changed how Bitbang library is used to facilitate multiple types of
    leds. See bitbang.c in the include folder for details.
    -Added a startup animation to the stat tracker
    -Fixed Main loop not running at LOOP_PERIOD_MS intervals.
    -
    [led-timings.csv]
2021-02-18 Updated Readme. Added Eagle source files.
    [HLD-stat-tracker-bottom-BOM.csv, HLD-stat-tracker-bottom.brd, HLD-stat-tracker-bottom.sch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]

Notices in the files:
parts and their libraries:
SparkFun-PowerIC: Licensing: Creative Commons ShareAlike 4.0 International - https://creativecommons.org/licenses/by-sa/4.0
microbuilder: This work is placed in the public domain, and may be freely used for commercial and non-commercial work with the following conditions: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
